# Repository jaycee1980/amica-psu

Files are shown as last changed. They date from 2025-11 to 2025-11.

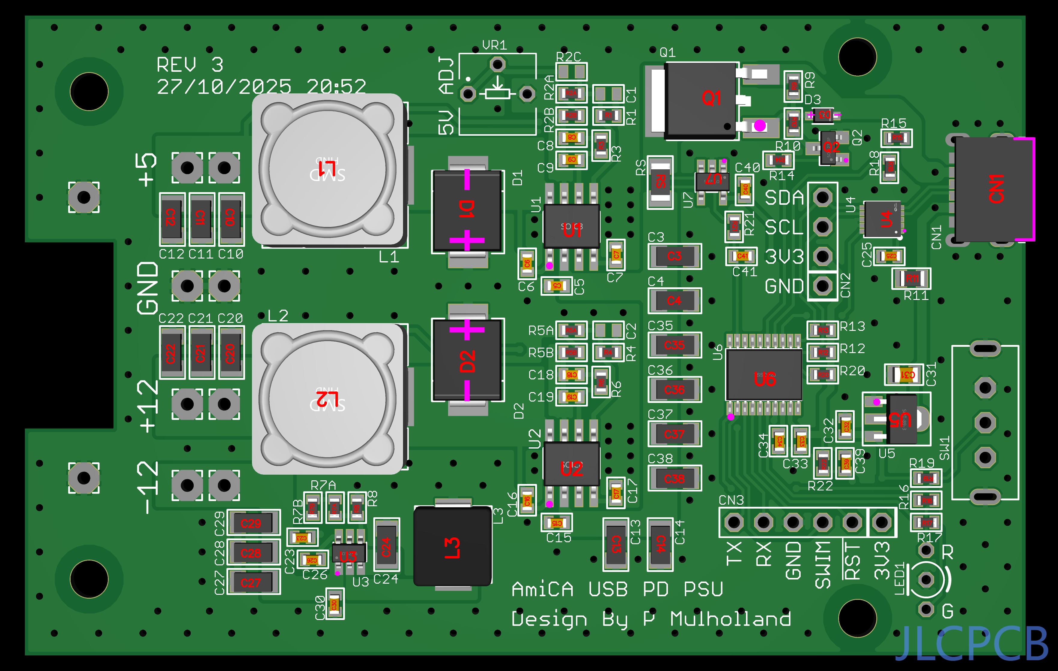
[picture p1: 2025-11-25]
pictures/capture-2025-11-25T15_29_06.361Z.jpg

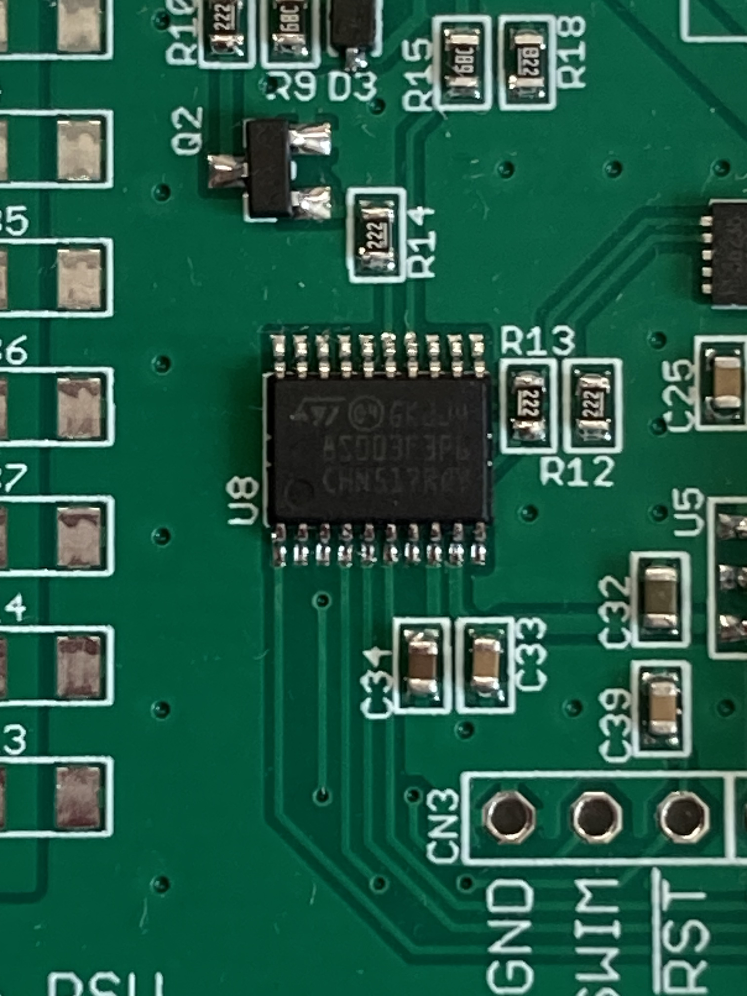
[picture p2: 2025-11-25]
pictures/IMG_4847.JPG

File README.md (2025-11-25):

# amica-psu
A USB PD power supply for Amiga computers

## PLEASE NOTE !!
This project is not yet finished ! The hardware is complete, but the firmware for the STM8 microcontroller is not finished. I decided to upload the project anyway rather than the work going to waste.
Hopefully if I can get my brain in working order, I will finish it.

## Does it even work?
The DC-DC conversion stuff works... see [here](https://youtu.be/czb_NR_QA5E) and [here](https://youtu.be/kD3LM56WTJc) to see it working
The HUSB238A works as it is being used in that second video on a breakout board. I have controlled the HUSB238 successfully using an Arduino.

## License
The hardware is licensed under the [Creative Commons non-commercial license](https://creativecommons.org/licenses/by-nc/4.0/)

The software is licensed under the [Zlib license](https://opensource.org/license/Zlib)

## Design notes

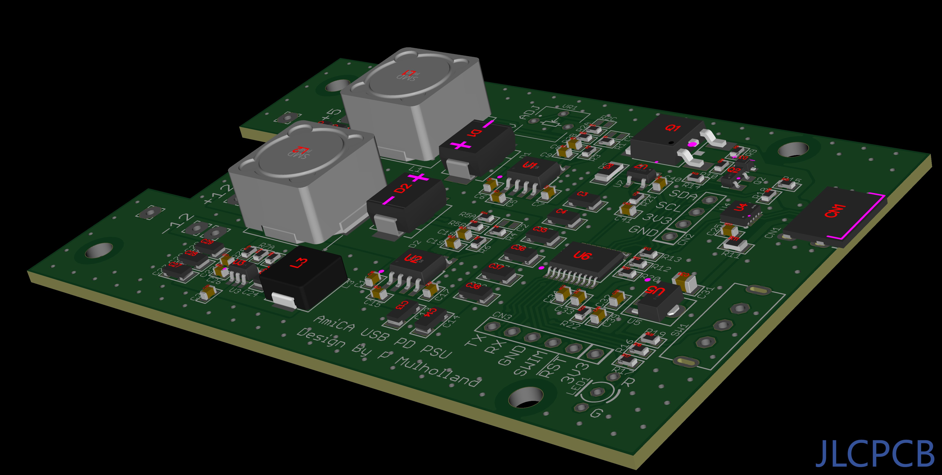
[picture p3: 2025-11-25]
pictures/capture-2025-11-25T15_30_16.297Z.jpg

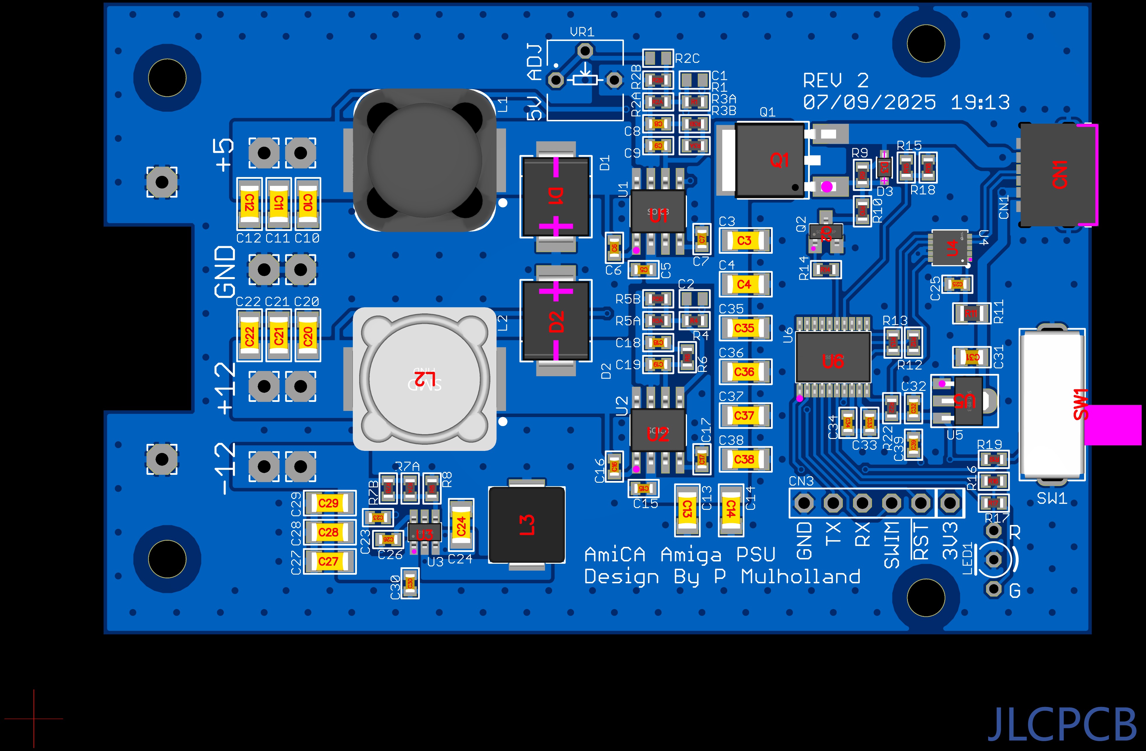
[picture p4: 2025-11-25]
pictures/capture-2025-09-08T19_42_13.009Z.jpg

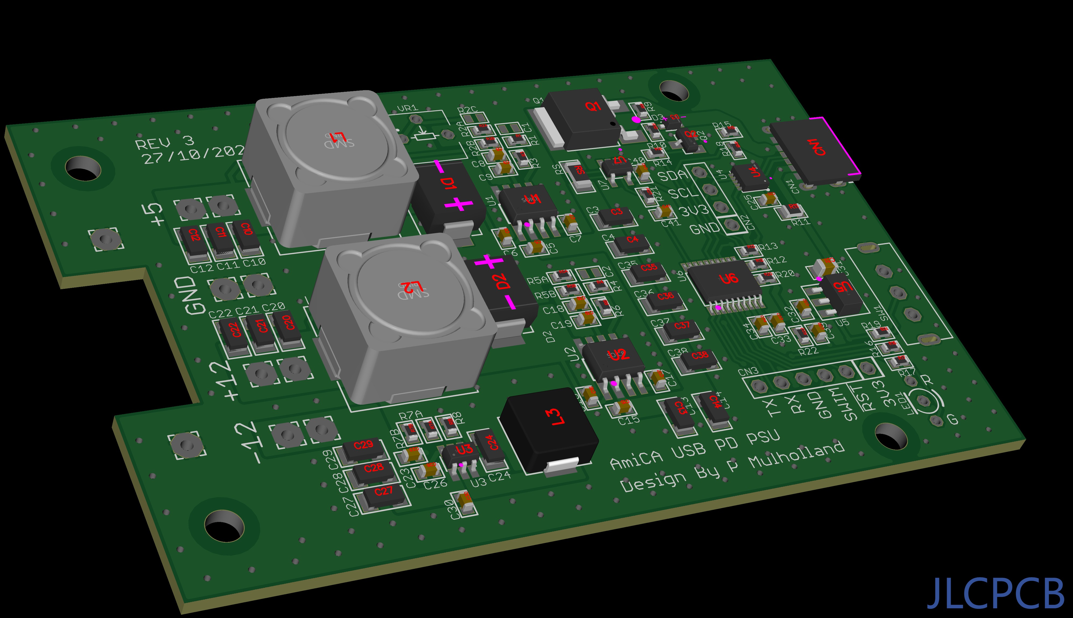
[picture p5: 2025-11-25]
pictures/capture-2025-11-25T15_29_34.894Z.jpg

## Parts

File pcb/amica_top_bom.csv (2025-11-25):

Comment | Designator | Footprint | LCSC Part #
0.012R | RS | 1206 | C601086
1K8 | R2A R7A R21 | 0603 | C4177
1n | C8 | 0603 | C1588
1u | C25 C34 | 0603 | C15849
2K2 | R10 R14 | 0603 | C4190
2n2 | C18 | 0603 | C1604
3K9 | R12 R13 | 0603 | C23018
6u8H | L1 | SHOUHAN_CYH125 | C2929498
8K2 | R18 | 0603 | C25981
10 | R11 | 0805 | C17415
10K | R1 R4 R6 | 0603 | C25804
10p | C9 C19 | 0603 | C1634
10u | C31 | 0805 | C15850
10u | C32 | 0603 | C19702
15uH | L2 | SHOUHAN_CYH125 | C2929500
22n | C7 C17 | 0603 | C21122
22u | C3 C4 C13 C14 C20 C21 C22 C24 C27 C28 C29 C35 C36 C37 C38 | 1206 | C12891
22uH | L3 | SHOUHAN_CYA0630 | C5189960
33 | R5B | 0603 | C23140
33K | R3 | 0603 | C4216
51K | R8 R9 R15 R19 R20 R22 | 0603 | C23196
100 | R2B | 0603 | C22775
100n | C5 C6 C15 C16 C23 C26 C30 C33 C39 C40 C41 | 0603 | C14663
100u | C10 C11 C12 | 1206 | C15008
330 | R16 R17 | 0603 | C23138
680 | R5A | 0603 | C23228
820 | R7B | 0603 | C23253
AOD4185 | Q1 | DPAK | C400894
BZT52C15S | D3 | SOD323F | C19077448
GCT_USB4125-GF-A | CN1 | GCT_USB4125-GF-A-0190_REVA2 | C18357552
HT7533-1 | U5 | SOT89 | C14289
HUSB238_002DD | U4 | DFN10-3X3 | C7471904
INA180A2IDBVR | U7 | SOT23-5 | C192764
MMBT3904 | Q2 | SOT23 | C7420353
SK84C | D1 D2 | SMC | C28646293
STM8S003F3P6 | U6 | TSSOP20 | C52717
TPS54202DDC | U3 | SOT23-6 | C191884
TPS54531DDA | U1 U2 | SO08-EP | C50605

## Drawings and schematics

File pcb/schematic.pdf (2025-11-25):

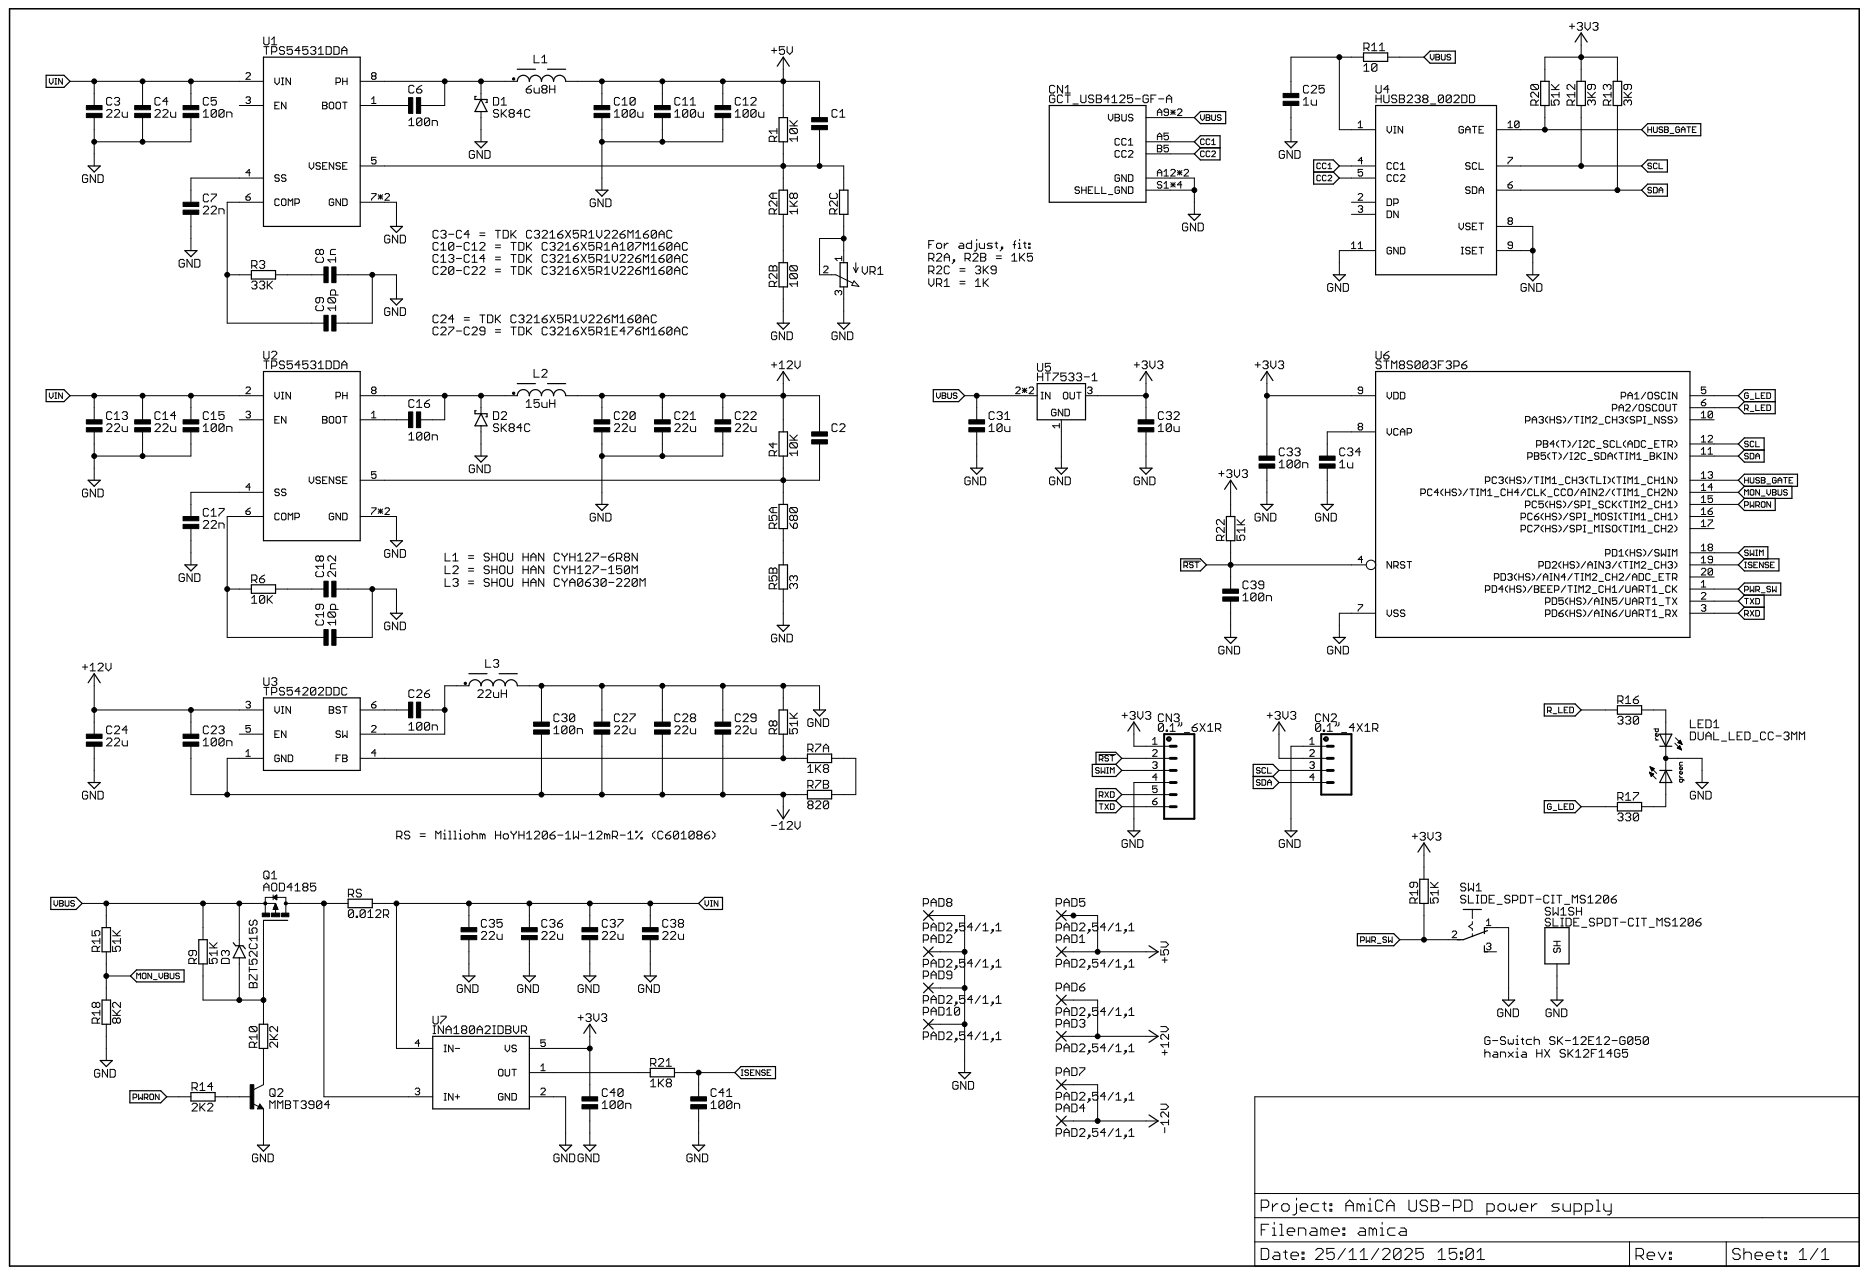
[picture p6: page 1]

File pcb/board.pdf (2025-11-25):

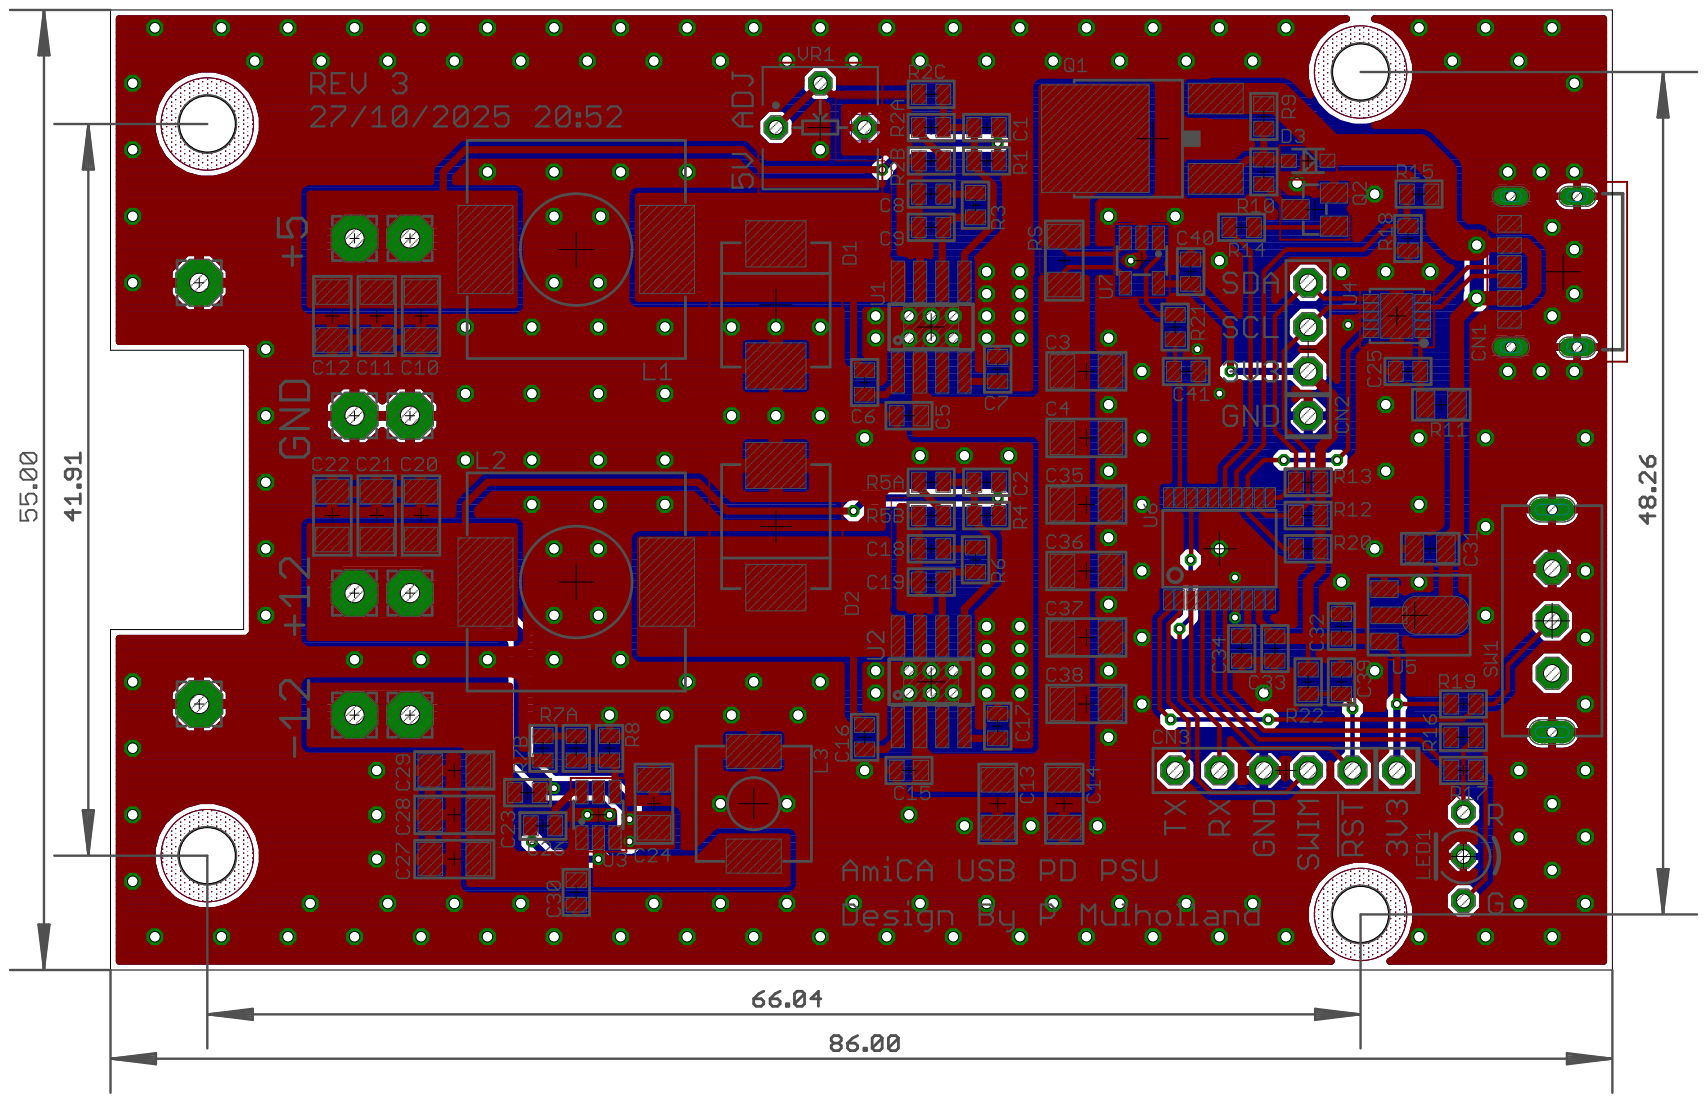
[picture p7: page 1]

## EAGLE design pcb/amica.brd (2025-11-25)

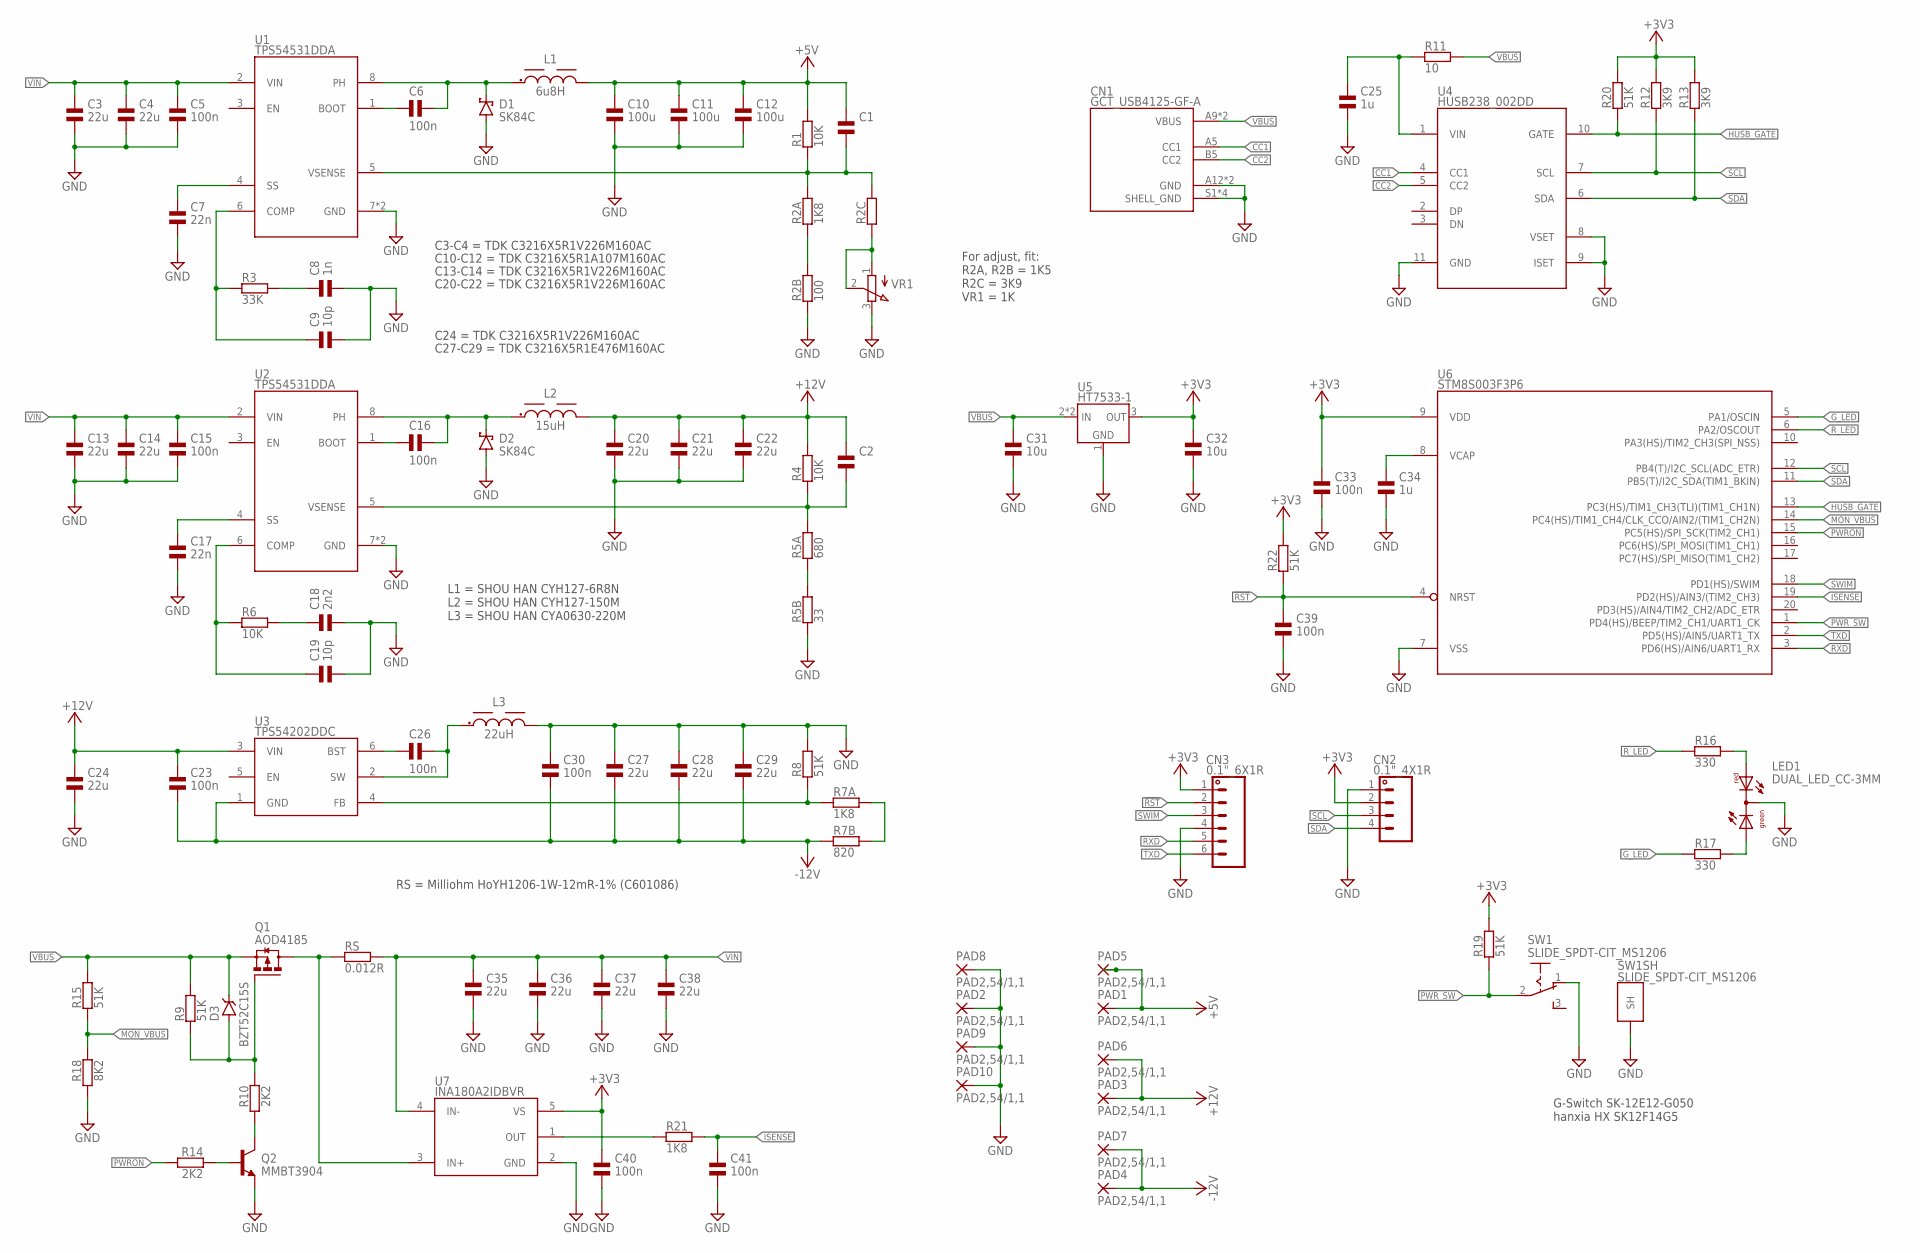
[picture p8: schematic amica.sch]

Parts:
C1, C2: CAP_NPOL-0603; 0603
C3, C4, C13, C14, C20, C21, C22, C24, C27, C28, C29, C35, C36, C37, C38: 22u; 1206; LCSC_PART C12891
C5, C6, C15, C16, C23, C26, C30, C33, C39, C40, C41: 100n; 0603; LCSC_PART C14663
C7, C17: 22n; 0603; LCSC_PART C21122
C8: 1n; 0603; LCSC_PART C1588
C9, C19: 10p; 0603; LCSC_PART C1634
C10, C11, C12: 100u; 1206; LCSC_PART C15008
C18: 2n2; 0603; LCSC_PART C1604
C25, C34: 1u; 0603; LCSC_PART C15849
C31: 10u; 0805; LCSC_PART C15850
C32: 10u; 0603; LCSC_PART C19702
CN1: GCT_USB4125-GF-A; GCT_USB4125-GF-A-0190_REVA2; LCSC_PART C18357552
CN2: 0.1"_4X1R; 0.1"_4X1-ROUND
CN3: 0.1"_6X1R; 0.1"_6X1-ROUND
D1, D2: SK84C; SMC; LCSC_PART C28646293
D3: BZT52C15S; SOD323F; LCSC_PART C19077448
L1: 6u8H; SHOUHAN_CYH125; LCSC_PART C2929498
L2: 15uH; SHOUHAN_CYH125; LCSC_PART C2929500
L3: 22uH; SHOUHAN_CYA0630; LCSC_PART C5189960
LED1: DUAL_LED_CC-3MM; DUOLED-3MM
PAD1, PAD2, PAD3, PAD4, PAD5, PAD6, PAD7, PAD8, PAD9, PAD10: PAD2,54/1,1; 2,54/1,1
Q1: AOD4185; DPAK; LCSC_PART C400894
Q2: MMBT3904; SOT23; LCSC_PART C7420353
R1, R4, R6: 10K; 0603; LCSC_PART C25804
R2A, R7A, R21: 1K8; 0603; LCSC_PART C4177
R2B: 100; 0603; LCSC_PART C22775
R2C: RES-SMD_0603; 0603
R3: 33K; 0603; LCSC_PART C4216
R5A: 680; 0603; LCSC_PART C23228
R5B: 33; 0603; LCSC_PART C23140
R7B: 820; 0603; LCSC_PART C23253
R8, R9, R15, R19, R20, R22: 51K; 0603; LCSC_PART C23196
R10, R14: 2K2; 0603; LCSC_PART C4190
R11: 10; 0805; LCSC_PART C17415
R12, R13: 3K9; 0603; LCSC_PART C23018
R16, R17: 330; 0603; LCSC_PART C23138
R18: 8K2; 0603; LCSC_PART C25981
RS: 0.012R; 1206; LCSC_PART C601086
SW1: SLIDE_SPDT-CIT_MS1206; CIT_MS1206; LCSC_PART C2848870
U1, U2: TPS54531DDA; SO08-EP; LCSC_PART C50605
U3: TPS54202DDC; SOT23-6; LCSC_PART C191884
U4: HUSB238_002DD; DFN10-3X3; LCSC_PART C7471904
U5: HT7533-1; SOT89; LCSC_PART C14289
U6: STM8S003F3P6; TSSOP20; LCSC_PART C52717
U7: INA180A2IDBVR; SOT23-5; LCSC_PART C192764
VR1: TRIMMER-BOURNS_3362P; TRIM_3362P-1

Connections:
5V_BST: C6.1, U1.1 (BOOT)
5V_COMP: C9.1, R3.1, U1.6 (COMP)
5V_FB: C1.2, R1.1, R2A.2, R2C.2, U1.5 (VSENSE)
5V_SS: C7.1, U1.4 (SS)
5V_SW: C6.2, D1.K (C), L1.P$1 (1), U1.8 (PH)
12V_BST: C16.1, U2.1 (BOOT)
12V_COMP: C19.1, R6.1, U2.6 (COMP)
12V_FB: C2.2, R4.1, R5A.2, U2.5 (VSENSE)
12V_SS: C17.1, U2.4 (SS)
12V_SW: C16.2, D2.K (C), L2.P$1 (1), U2.8 (PH)
!RST: C39.1, CN3.2, R22.1, U6.4 (NRST)
+3V3: C32.1, C33.1, C40.1, CN2.2, CN3.1, R12.2, R13.2, R19.2, R20.2, R22.2, U5.3 (OUT), U6.9 (VDD), U7.5 (VS)
+5V: C1.1, C10.1, C11.1, C12.1, L1.P$2 (2), PAD1.1, PAD5.1, R1.2
+12V: C2.1, C20.1, C21.1, C22.1, C23.1, C24.1, L2.P$2 (2), PAD3.1, PAD6.1, R4.2, U3.3 (VIN)
-12V: C23.2, C27.2, C28.2, C29.2, C30.2, PAD4.1, PAD7.1, R7B.1, U3.1 (GND)
-12V_BST: C26.1, U3.6 (BST)
-12V_FB: R7A.1, R8.1, U3.4 (FB)
-12V_SW: C26.2, L3.P$1 (1), U3.2 (SW)
CC1: CN1.A5 (CC1), U4.4 (CC1)
CC2: CN1.B5 (CC2), U4.5 (CC2)
GND: C3.2, C4.2, C5.2, C7.2, C8.2, C9.2, C10.2, C11.2, C12.2, C13.2, C14.2, C15.2, C17.2, C18.2, C19.2, C20.2, C21.2, C22.2, C24.2, C25.2, C27.1, C28.1, C29.1, C30.1, C31.2, C32.2, C33.2, C34.2, C35.2, C36.2, C37.2, C38.2, C39.2, C40.2, C41.2, CN1.A12 (GND), CN1.B12 (GND), CN1.S1 (SHELL_GND), CN1.S2 (SHELL_GND), CN1.S3 (SHELL_GND), CN1.S4 (SHELL_GND), CN2.1, CN3.4, D1.A, D2.A, L3.P$2 (2), LED1.COM (C), PAD2.1, PAD8.1, PAD9.1, PAD10.1, Q2.2 (E), R2B.1, R5B.1, R8.2, R18.2, SW1.1 (O), SW1.GND@1 (SH), SW1.GND@2 (SH), U1.7 (GND), U1.PAD (GND), U2.7 (GND), U2.PAD (GND), U4.8 (VSET), U4.9 (ISET), U4.11 (GND), U5.1 (GND), U6.7 (VSS), U7.2 (GND), VR1.3 (CW)
G_LED: R17.1, U6.5 (PA1/OSCIN)
HUSB_GATE: R20.1, U4.10 (GATE), U6.13 (PC3(HS)/TIM1_CH3(TLI)(TIM1_CH1N))
HUSB_VIN: C25.1, R11.1, U4.1 (VIN)
ISENSE: C41.1, R21.2, U6.19 (PD2(HS)/AIN3/(TIM2_CH3))
MON_VBUS: R15.1, R18.1, U6.14 (PC4(HS)/TIM1_CH4/CLK_CCO/AIN2/(TIM1_CH2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)
unnamed: D3.A, Q1.1 (G), R9.1, R10.1
unnamed: LED1.2 (AR), R16.2
unnamed: R2A.1, R2B.2
unnamed: R2C.1, VR1.1 (CCW), VR1.2 (W)
unnamed: C18.1, R6.2
unnamed: C34.1, U6.8 (VCAP)
unnamed: LED1.1 (AG), R17.2
unnamed: Q2.1 (B), R14.1
unnamed: R5A.1, R5B.2
unnamed: C8.1, R3.2
unnamed: R21.1, U7.1 (OUT)
unnamed: R7A.2, R7B.2
unnamed: Q2.3 (C), R10.2
PWRON: R14.2, U6.15 (PC5(HS)/SPI_SCK(TIM2_CH1))
PWR_SW: R19.1, SW1.2, U6.1 (PD4(HS)/BEEP/TIM2_CH1/UART1_CK)
RXD: CN3.5, U6.3 (PD6(HS)/AIN6/UART1_RX)
R_LED: R16.1, U6.6 (PA2/OSCOUT)
SCL: CN2.3, R12.1, U4.7 (SCL), U6.12 (PB4(T)/I2C_SCL(ADC_ETR))
SDA: CN2.4, R13.1, U4.6 (SDA), U6.11 (PB5(T)/I2C_SDA(TIM1_BKIN))
SWIM: CN3.3, U6.18 (PD1(HS)/SWIM)
TXD: CN3.6, U6.2 (PD5(HS)/AIN5/UART1_TX)
VBUS: C31.1, CN1.A9 (VBUS), CN1.B9 (VBUS), D3.C, Q1.3 (S), R9.2, R11.2, R15.2, U5.2 (IN), U5.2@1 (IN)
VBUS_SW: Q1.4 (D), RS.1, U7.3 (IN+)
VIN: C3.1, C4.1, C5.1, C13.1, C14.1, C15.1, C35.1, C36.1, C37.1, C38.1, RS.2, U1.2 (VIN), U2.2 (VIN), U7.4 (IN-)

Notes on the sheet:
C20-C22 = TDK C3216X5R1V226M160AC
C10-C12 = TDK C3216X5R1A107M160AC
C13-C14 = TDK C3216X5R1V226M160AC
C3-C4 = TDK C3216X5R1V226M160AC
C24 = TDK C3216X5R1V226M160AC
C27-C29 = TDK C3216X5R1E476M160AC
G-Switch SK-12E12-G050 hanxia HX SK12F14G5
For adjust, fit: R2A, R2B = 1K5 R2C = 3K9 VR1 = 1K
L1 = SHOU HAN CYH127-6R8N L2 = SHOU HAN CYH127-150M L3 = SHOU HAN CYA0630-220M
RS = Milliohm HoYH1206-1W-12mR-1% (C601086)

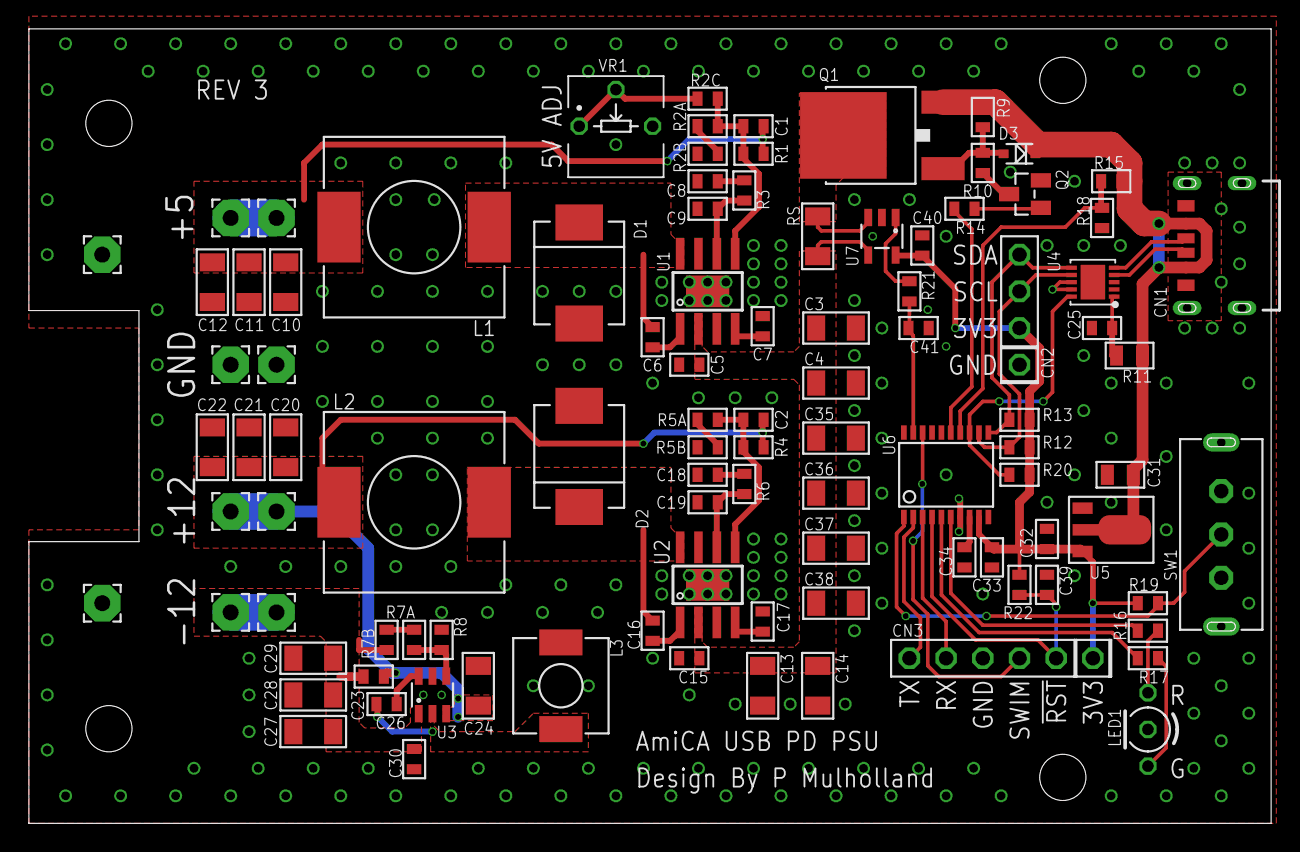
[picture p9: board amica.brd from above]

Board: 2 copper layers, 86.0 x 55.0 mm, 99 parts (0 on the bottom side), 50 nets.

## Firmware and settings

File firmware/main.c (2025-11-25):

/*******************************************************************************************************************//**
	AmiCA USB PD power supply
	\author Peter Mulholland
***********************************************************************************************************************/

#define F_CPU	8000000UL
#define STM8S003

#include <stdint.h>
#include <stdio.h>
#include <string.h>

#include "stm8s.h"

#include "husb238.h"

//----------------------------------------------------------------------------------------------------------------------
// Definitions
/*
	STM8S003F3P6

	PA1		GPIO_Output, Green LED
	PA2		GPIO_Output, Red LED
	PA3		GPIO_Input, HUSB238 "GATE" pin state

	PB4		I2C_SCL
	PB5		I2C_SDA

	PC4		ADC_IN2 - VBUS voltage
	PC5		GPIO_Output, PWRON (high = on)

	PD1		SWIM
	PD2		ADC_IN3 - current sense 
	PD4		GPIO_Input, Power switch (low = on)
	PD5		UART1_TXD
	PD6		UART1_RXD
*/

// Bits to set in PA_ODR for the LEDs
#define RED_LED		(1 << 2)
#define GREEN_LED	(1 << 1)
#define AMBER_LED	((1 << 1) | (1 << 2))

//#define _DEBUG

// Retry I2C this many times before giving up
#define MAX_I2C_TRIES		5

#define MAX_ATTACH_TRIES	5

//----------------------------------------------------------------------------------------------------------------------
// Global variables

uint8_t volatile outon;

//----------------------------------------------------------------------------------------------------------------------
// Local Functions

inline void delay_ms(uint32_t ms)
 {
	for (uint32_t i = 0; i < ((F_CPU / 18 / 1000UL) * ms); i++)
		__asm__("nop");
}

#ifdef _DEBUG
int putchar(int c)
{
	UART1_SendData8((uint8_t) c);
	while(UART1_GetFlagStatus(UART1_FLAG_TC) == RESET)
		;

	return 0;
}
#endif

void i2c_sendaddr(uint8_t Address, I2C_Direction_TypeDef Direction)
{
	for(ErrorStatus match = ERROR, nack = ERROR; !match;)
	{
		I2C_Send7bitAddress(Address, Direction);

		do
		{
			nack = I2C_CheckEvent(I2C_EVENT_SLAVE_ACK_FAILURE);

			match = (Direction == I2C_DIRECTION_TX) ?
				I2C_CheckEvent(I2C_EVENT_MASTER_TRANSMITTER_MODE_SELECTED) :
				I2C_CheckEvent(I2C_EVENT_MASTER_RECEIVER_MODE_SELECTED);
		} while (!match || nack);

		if (nack)
			puts("i2c_sendaddr: Address NACK!");
	}
}

void husb238_write_reg(uint8_t reg, uint8_t val)
{
	while(I2C_GetFlagStatus(I2C_FLAG_BUSBUSY))
		;

	I2C_GenerateSTART(ENABLE);
	while (!I2C_CheckEvent(I2C_EVENT_MASTER_MODE_SELECT))
		;

	i2c_sendaddr(HUSB238_I2CADDR, I2C_DIRECTION_TX);

	I2C_SendData(reg);
	while (!I2C_CheckEvent(I2C_EVENT_MASTER_BYTE_TRANSMITTED))
	{
		if (I2C_CheckEvent(I2C_EVENT_SLAVE_ACK_FAILURE))
			puts("husb238_write_reg: register Tx NACK!");
	}

	I2C_SendData(val);
	while (!I2C_CheckEvent(I2C_EVENT_MASTER_BYTE_TRANSMITTED))
	{
		if (I2C_CheckEvent(I2C_EVENT_SLAVE_ACK_FAILURE))
			puts("husb238_write_reg: value Tx NACK!");
	}

	I2C_GenerateSTOP(ENABLE);
}

void husb238_read_reg(uint8_t reg, uint8_t *val)
{
	while(I2C_GetFlagStatus(I2C_FLAG_BUSBUSY))
		;

	I2C_GenerateSTART(ENABLE);
	while (!I2C_CheckEvent(I2C_EVENT_MASTER_MODE_SELECT))
		;

	i2c_sendaddr(HUSB238_I2CADDR, I2C_DIRECTION_TX);

	I2C_SendData(reg);
	while (!I2C_CheckEvent(I2C_EVENT_MASTER_BYTE_TRANSMITTED))
	{
		if (I2C_CheckEvent(I2C_EVENT_SLAVE_ACK_FAILURE))
			puts("husb238_read_reg: register Tx NACK!");
	}

	I2C_GenerateSTART(ENABLE);

	while(!I2C_CheckEvent(I2C_EVENT_MASTER_MODE_SELECT))
		;

	i2c_sendaddr(HUSB238_I2CADDR, I2C_DIRECTION_RX);

	I2C_AcknowledgeConfig(I2C_ACK_NONE);
	I2C_GenerateSTOP(ENABLE);

	while (!I2C_CheckEvent(I2C_EVENT_MASTER_BYTE_RECEIVED))
		;

	*val = I2C_ReceiveData();
}

//----------------------------------------------------------------------------------------------------------------------
// ISRs

void trap_isr(void) __trap
{
	// A trap wil cause the LED to blink Amber/Red
	disable_interrupts();
	while(1)
	{
		PA_ODR = AMBER_LED;
		delay_ms(500);
		PA_ODR = RED_LED;
		delay_ms(500);
	}
}

// IRQ when HUSB238 GATE pin changes
void porta_isr(void) __interrupt(EXTI0_ISR)
{
//	gateon = ((PA_IDR & (1<<3)) == 0);
}

// IRQ when power switch state changes
void portc_isr(void) __interrupt(EXTI3_ISR)
{
//	outon = ((PD_IDR & (1<<4)) == 0);
}

// IRQ on TIM1 
void tim1_isr(void) __interrupt(TIM1_OVF_ISR)
{
}

//----------------------------------------------------------------------------------------------------------------------
// Main

void main(void)
{
	// ------------------------------------------------------------------------
	// Configure system clocks

	// Use HSI clock at 8MHz (default)
	//CLK_CKDIVR = 0x18;				// HSI / 8, CPU / 1

	// Enable clock for I2C, UART1, ADC and TIMER1
	CLK_PCKENR1 = (CLK_PCKENR1_I2C | CLK_PCKENR1_UART1 | CLK_PCKENR1_TIM1);
	CLK_PCKENR2 = CLK_PCKENR2_ADC;

	// ------------------------------------------------------------------------
	// Configure GPIO pins

	// Port A
	// PA1 GPIO_Output, Green LED
	// PA2 GPIO_Output, Red LED
	// PA3 GPIO_Input, HUSB238 "GATE" pin state

	PA_DDR = 0b00000110;			// PA1-2 output, PA3 input
	PA_CR1 = 0b00000110;			// PA1-2 p-p out, PA3 no pullup
	PA_CR2 = 0b00001000;			// PA1-2 2MHz out, PA3 interrupt

	// Port B - PB4 and PB5 are used for I2C

	PB_DDR = 0;
	PB_CR1 = PB_CR2 = 0;

	// Port C
	// PC3 = unused
	// PC4 = ADC_IN2 - VBUS voltage
	// PC5 = GPIO_Output, output on (high = on)
	// PC6 = unused
	// PC7 = unused
	
	PC_DDR = 0b00100000;			// PC5 output, all others input
	PC_CR1 = 0b00100000;			// PC5 p-p out
	PC_CR2 = 0b00000000;			// PC5 2MHz out

	// Port D
	// PD1 = SWIM
	// PD2 = ADC_IN3 - current sense 
	// PD3 = not used
	// PD4 = GPIO_Input, Power switch (low = on)
	// PD5 = UART1_TXD
	// PD6 = UART1_RXD

	PD_DDR = 0b00000000;			// All inputs
	PD_CR1 = 0b00010010;			// PD4 pullup on, SWIM pullup on
	PD_CR2 = 0b00010000;			// PD4 interrupt on state change

	// ------------------------------------------------------------------------
	// Configure ADC

	ADC1_TDRL = 0xFF;					// Disable input schmitt triggers
	ADC1_TDRH = 0xFF;
	
	ADC1_CSR = 2;						// no EOC interrupt, no analog watchdog, default to ADC_IN2

	ADC1_CR3 = 0;						// No data buffer
	ADC1_CR2 = (1 << ADC1_CR2_ALIGN);	// RH aligned data
	ADC1_CR1 = (1 << ADC1_CR1_ADON);	// Clock prescaler /2, Single shot mode, enable

	// ------------------------------------------------------------------------
	// Configure interrupt controller

	// PDIS = 11 (rising and falling edge interrupts)
	// PCIS = 11 (rising and falling edge interrupts)
	EXTI_CR1 = (1<<7) | (1<<6) | (1<<5) | (1<<4);
	EXTI_CR2 = 0;

	// ------------------------------------------------------------------------
	// If debug build, Initialise UART 1

	#ifdef _DEBUG
		UART1_Init(9600, UART1_WORDLENGTH_8D, UART1_STOPBITS_1, UART1_PARITY_NO, UART1_SYNCMODE_CLOCK_DISABLE, UART1_MODE_TXRX_ENABLE);
		UART1_Cmd(ENABLE);
		(void) UART1_SR;	// dummy read - clear the status register
	#endif

	// ------------------------------------------------------------------------
	// Initialise I2C bus

	I2C_Init(100000, 0x00, I2C_DUTYCYCLE_2, I2C_ACK_CURR, I2C_ADDMODE_7BIT, F_CPU / 1000000UL);
	I2C_Cmd(ENABLE);

	// ------------------------------------------------------------------------
	// Wait for the HUSB238 to attach to the PD source

	PA_ODR = RED_LED;

	bool is_attached = false;
	for (int try = 0; try < MAX_ATTACH_TRIES; try++)
	{
		uint8_t sr1;
		husb238_read_reg(HUSB238_PD_STATUS1, &sr1);

		// Are we attached?
		if (sr1 & HUSB238_STATUS1_ATTACH)
		{
			is_attached = true;
			break;
		}

		// Wait a little while and retry
		delay_ms(500);
	}

	if (!is_attached)
	{
		// We cant attach - either a cable issue or the source isnt PD
		// Blink LED red and stop
	}

	// ------------------------------------------------------------------------
	// Look at the supported PDOs and find one to use

	uint8_t selected_pdo = 0;

	for (uint8_t pdoreg = HUSB238_SRC_PDO_15V; pdoreg <= HUSB238_SRC_PDO_20V; pdoreg++)
	{
		uint8_t pdoval;

		// Read this PDO's data
		husb238_read_reg(pdoreg, &pdoval)

		// Is it supported ? If not, try the next one
		if ((pdoval & 0x80) == 0)
			continue;

		// Can we support at least 2.5A ?
		if ((pdoval & 0x0F) >= CURRENT_2_50_A)
		{
			selected_pdo = pdoreg;
			break;
		}
	}

	// Did we get a usable PDO?
	if (selected_pdo == 0)
	{
		// Cant find a usable PDO
		// Blink LED red and stop
	}

	// ------------------------------------------------------------------------
	// Select the PDO

	husb238_write_reg(HUSB238_SRC_PDO,(uint8_t) selected_pdo << 4);
	husb238_write_reg(HUSB238_GO_COMMAND, HUSB238_CMD_REQUEST_PDO);

	// Wait for it to take effect
	
	for (;;)
	{
		uint8_t sr0, pdo_voltage, pdo_current;
		husb238_read_reg(HUSB238_PD_STATUS0, &sr0);

		pdo_voltage = (sr0 >> 4) & 0x0f;
		pdo_current = sr0 & 0x0f

		if (pdo_voltage == selected_pdo)
			break;

		// TODO timeout here?
	}

	// ------------------------------------------------------------------------
	// Loop here

	while (1)
	{
		bool outon = ((PD_IDR & (1<<4)) == 0);

		// Update output state

		if (outon)
		{
			// power on
			PC_ODR |= (1 << 5);
			PA_ODR = GREEN_LED;
		}
		else
		{
			// power off
			PC_ODR &= ~(1 << 5);
			PA_ODR = RED_LED;
		}

		// Wait for interrupt
		__asm__("wfi");
	}

	// We shouldnt get here!
	disable_interrupts();
	halt();
}

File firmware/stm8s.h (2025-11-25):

#ifndef STM8S_H
#define STM8S_H

#include <stdint.h>



#define __I		volatile const	/*!< defines 'read only' permissions     */
#define __O		volatile		/*!< defines 'write only' permissions    */
#define __IO	volatile		/*!< defines 'read / write' permissions  */


#define CONST const
#define assert_param(x)

typedef enum {RESET = 0, SET = !RESET} FlagStatus, ITStatus, BitStatus, BitAction;

typedef enum {DISABLE = 0, ENABLE = !DISABLE} FunctionalState;
#define IS_FUNCTIONALSTATE_OK(STATE) (((STATE) == DISABLE) || ((STATE) == ENABLE))

typedef enum {ERROR = 0, SUCCESS = !ERROR} ErrorStatus;


#define _MEM_(mem_addr)			(*(volatile uint8_t *)(mem_addr))
#define _SFR_(mem_addr)			(*(volatile uint8_t *)((mem_addr)))
#define _SFR16_(mem_addr)		(*(volatile uint16_t *)((mem_addr)))

/* PORT A */
#define PA_BASE_ADDRESS         0x5000
#define PA_ODR                  _SFR_(PA_BASE_ADDRESS + 0x00)
#define PA_IDR                  _SFR_(PA_BASE_ADDRESS + 0x01)
#define PA_DDR                  _SFR_(PA_BASE_ADDRESS + 0x02)
#define PA_CR1                  _SFR_(PA_BASE_ADDRESS + 0x03)
#define PA_CR2                  _SFR_(PA_BASE_ADDRESS + 0x04)

/* PORT B */
#define PB_BASE_ADDRESS         0x5005
#define PB_ODR                  _SFR_(PB_BASE_ADDRESS + 0x00)
#define PB_IDR                  _SFR_(PB_BASE_ADDRESS + 0x01)
#define PB_DDR                  _SFR_(PB_BASE_ADDRESS + 0x02)
#define PB_CR1                  _SFR_(PB_BASE_ADDRESS + 0x03)
#define PB_CR2                  _SFR_(PB_BASE_ADDRESS + 0x04)

/* PORT C */
#define PC_BASE_ADDRESS         0x500A
#define PC_ODR                  _SFR_(PC_BASE_ADDRESS + 0x00)
#define PC_IDR                  _SFR_(PC_BASE_ADDRESS + 0x01)
#define PC_DDR                  _SFR_(PC_BASE_ADDRESS + 0x02)
#define PC_CR1                  _SFR_(PC_BASE_ADDRESS + 0x03)
#define PC_CR2                  _SFR_(PC_BASE_ADDRESS + 0x04)

/* PORT D */
#define PD_BASE_ADDRESS         0x500F
#define PD_ODR                  _SFR_(PD_BASE_ADDRESS + 0x00)
#define PD_IDR                  _SFR_(PD_BASE_ADDRESS + 0x01)
#define PD_DDR                  _SFR_(PD_BASE_ADDRESS + 0x02)
#define PD_CR1                  _SFR_(PD_BASE_ADDRESS + 0x03)
#define PD_CR2                  _SFR_(PD_BASE_ADDRESS + 0x04)

/* PORT E */
#define PE_BASE_ADDRESS         0x5014
#define PE_ODR                  _SFR_(PE_BASE_ADDRESS + 0x00)
#define PE_IDR                  _SFR_(PE_BASE_ADDRESS + 0x01)
#define PE_DDR                  _SFR_(PE_BASE_ADDRESS + 0x02)
#define PE_CR1                  _SFR_(PE_BASE_ADDRESS + 0x03)
#define PE_CR2                  _SFR_(PE_BASE_ADDRESS + 0x04)

/* PORT F */
#define PF_BASE_ADDRESS         0x5019
#define PF_ODR                  _SFR_(PF_BASE_ADDRESS + 0x00)
#define PF_IDR                  _SFR_(PF_BASE_ADDRESS + 0x01)
#define PF_DDR                  _SFR_(PF_BASE_ADDRESS + 0x02)
#define PF_CR1                  _SFR_(PF_BASE_ADDRESS + 0x03)
#define PF_CR2                  _SFR_(PF_BASE_ADDRESS + 0x04)

/* PORT G */
#define PG_BASE_ADDRESS         0x501E
#define PG_ODR                  _SFR_(PG_BASE_ADDRESS + 0x00)
#define PG_IDR                  _SFR_(PG_BASE_ADDRESS + 0x01)
#define PG_DDR                  _SFR_(PG_BASE_ADDRESS + 0x02)
#define PG_CR1                  _SFR_(PG_BASE_ADDRESS + 0x03)
#define PG_CR2                  _SFR_(PG_BASE_ADDRESS + 0x04)

/* PORT H */
#define PH_BASE_ADDRESS         0x5023
#define PH_ODR                  _SFR_(PH_BASE_ADDRESS + 0x00)
#define PH_IDR                  _SFR_(PH_BASE_ADDRESS + 0x01)
#define PH_DDR                  _SFR_(PH_BASE_ADDRESS + 0x02)
#define PH_CR1                  _SFR_(PH_BASE_ADDRESS + 0x03)
#define PH_CR2                  _SFR_(PH_BASE_ADDRESS + 0x04)

/* PORT I */
#define PI_BASE_ADDRESS         0x5028
#define PI_ODR                  _SFR_(PI_BASE_ADDRESS + 0x00)
#define PI_IDR                  _SFR_(PI_BASE_ADDRESS + 0x01)
#define PI_DDR                  _SFR_(PI_BASE_ADDRESS + 0x02)
#define PI_CR1                  _SFR_(PI_BASE_ADDRESS + 0x03)
#define PI_CR2                  _SFR_(PI_BASE_ADDRESS + 0x04)

/* Flash */
#define FLASH_BASE_ADDRESS      0x505A
#define FLASH_CR1               _SFR_(FLASH_BASE_ADDRESS + 0x00)
#define FLASH_CR1_HALT          3
#define FLASH_CR1_AHALT         2
#define FLASH_CR1_IE            1
#define FLASH_CR1_FIX           0
#define FLASH_CR2               _SFR_(FLASH_BASE_ADDRESS + 0x01)
#define FLASH_CR2_OPT           7
#define FLASH_CR2_WPRG          6
#define FLASH_CR2_ERASE         5
#define FLASH_CR2_FPRG          4
#define FLASH_CR2_PRG           0
#define FLASH_NCR2              _SFR_(FLASH_BASE_ADDRESS + 0x02)
#define FLASH_NCR2_NOPT         7
#define FLASH_NCR2_NWPRG        6
#define FLASH_NCR2_NERASE       5
#define FLASH_NCR2_NFPRG        4
#define FLASH_NCR2_NPRG         0
#define FLASH_FPR               _SFR_(FLASH_BASE_ADDRESS + 0x03)
#define FLASH_NFPR              _SFR_(FLASH_BASE_ADDRESS + 0x04)
#define FLASH_IAPSR             _SFR_(FLASH_BASE_ADDRESS + 0x05)
#define FLASH_IAPSR_DUL         3
#define FLASH_IAPSR_EOP         2
#define FLASH_IAPSR_PUL         1
#define FLASH_PUKR              _SFR_(FLASH_BASE_ADDRESS + 0x08)
#define FLASH_PUKR_KEY1         0x56
#define FLASH_PUKR_KEY2         0xAE
#define FLASH_DUKR              _SFR_(FLASH_BASE_ADDRESS + 0x0A)
#define FLASH_DUKR_KEY1         FLASH_PUKR_KEY2
#define FLASH_DUKR_KEY2         FLASH_PUKR_KEY1

/* EXTI */
#define EXTI_BASE_ADDRESS       0x50A0
#define EXTI_CR1                _SFR_(EXTI_BASE_ADDRESS + 0x00)
#define EXTI_CR2                _SFR_(EXTI_BASE_ADDRESS + 0x01)

/* RST */
#define RST_BASE_ADDRESS        0x50B3
#define RST_SR                  _SFR_(RST_BASE_ADDRESS + 0x00)

/* Clock */
#define CLK_BASE_ADDRESS        0x50C0
#define CLK_ICKR                _SFR_(CLK_BASE_ADDRESS + 0x00)
#define CLK_ECKR                _SFR_(CLK_BASE_ADDRESS + 0x01)
#define CLK_CMSR                _SFR_(CLK_BASE_ADDRESS + 0x03)
#define CLK_SWR                 _SFR_(CLK_BASE_ADDRESS + 0x04)
#define CLK_SWCR                _SFR_(CLK_BASE_ADDRESS + 0x05)
#define CLK_CKDIVR              _SFR_(CLK_BASE_ADDRESS + 0x06)
#define CLK_PCKENR1             _SFR_(CLK_BASE_ADDRESS + 0x07)
#define CLK_CSSR                _SFR_(CLK_BASE_ADDRESS + 0x08)
#define CLK_CCOR                _SFR_(CLK_BASE_ADDRESS + 0x09)
#define CLK_PCKENR2             _SFR_(CLK_BASE_ADDRESS + 0x0A)
#define CLK_HSITRIMR            _SFR_(CLK_BASE_ADDRESS + 0x0C)
#define CLK_SWIMCCR             _SFR_(CLK_BASE_ADDRESS + 0x0D)

//#define CLK_ICKR_REGAH          5
//#define CLK_ICKR_LSIRDY         4
//#define CLK_ICKR_LSIEN          3
//#define CLK_ICKR_FHWU           2
//#define CLK_ICKR_HSIRDY         1
//#define CLK_ICKR_HSIEN          0
//#define CLK_ECKR_HSERDY         1
//#define CLK_ECKR_HSEEN          0
//#define CLK_SWCR_SWIF           3
//#define CLK_SWCR_SWIEN          2
//#define CLK_SWCR_SWEN           1
//#define CLK_SWCR_SWBSY          0
//#define CLK_CCOR_CCOEN          0
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

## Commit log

2025-11-25 Updated schematic to correct R7A/R7B resistor values
2025-11-25 Added EAGLE files
    [amica.brd, amica.sch]
